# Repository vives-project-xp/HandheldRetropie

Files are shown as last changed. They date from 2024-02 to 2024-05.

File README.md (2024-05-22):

# HandheldRetropie
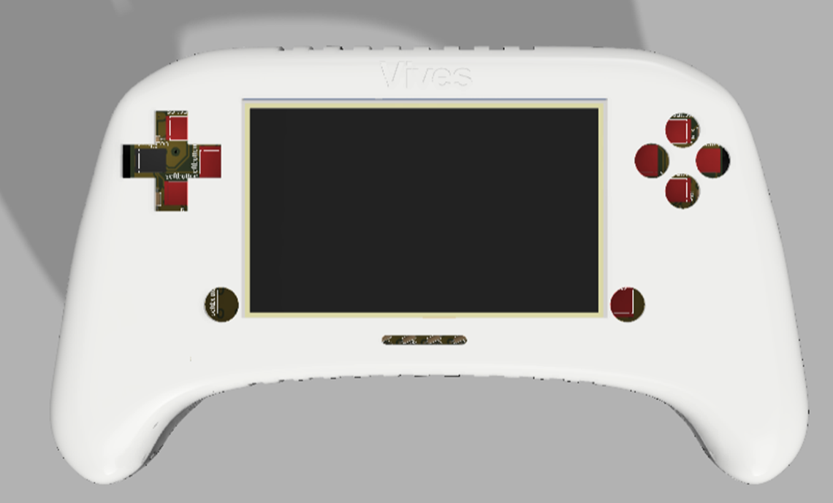
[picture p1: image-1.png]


These pictures are early renders of how the project should look.

## Contents

1. Introduction

2. The Team

3. Features

4. Software

5. 3D prints

6. PCB design

7. Hardware

8. setup

9. Tests

10. BOM

11. Information about the project

## Introduction
Welcome to the RetroPie Project! RetroPie is a versatile software solution that allows you to transform your Raspberry Pi into a full-fledged retro gaming console. It takes you back to the golden days of gaming where the concept was very simple but still fun. So you can play all the classic games you want, from Tetris to Mario. It does take you back to your childhood.

## The team

Thibaut Schroyens: Scrummaster, PCB design

Ruben Belligh: 3D design

Joë Boone: electronics

## Features
 
- The console is battery-powered.
- You can  switch the batterys.
- Designing PCB so that it takes up as little space as possible.
- Custom made casing.
- Uploading new games trough wifi.
- Battery indicator.
- Active cooling with PWM fans.
- Build in speaker.

## Software
One of the essential parts of the Retropie and maybe the beating heart of the project is the emulator. This is a software that makes it possible to put older games on a recent console. They actually form a bridge between the present and the past. This allows gamers to enjoy old games without playing on an old console. There will be a program running parallel with the games that calculates a PWM signal for cooling the system. This is calculated by the temperature inside the processor. the hotter it gets, the higher the PWM duty cycle gets, and thus cooling the system more.

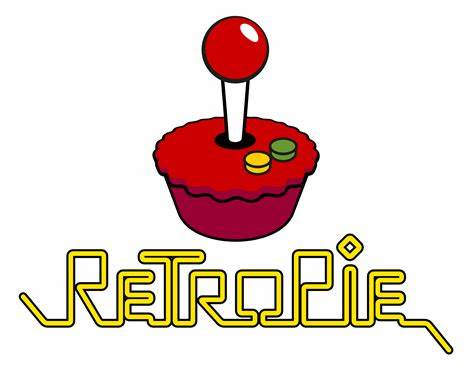
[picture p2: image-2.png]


## 3d prints
We've devided the 3d print in multiple parts so that these are easier to print. That's why there are 6 diffrent parts for the controller itself. The rest of the prints are the buttons. The controller can be connected trough connecting points that need to be glued together, this is only for the top side. The bottom side will be mounted with screws to the topside.
All of our prints were designed with fusion 360, the instructions to design certain models is in the 'handleiding fusion 360' folder.

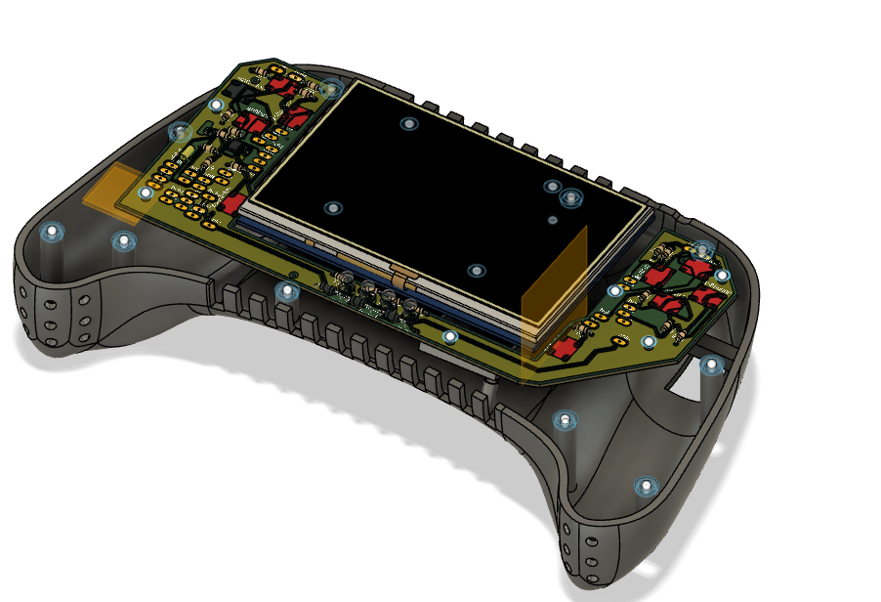
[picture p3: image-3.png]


## PCB design
Our pcb is also designed with fusion 360. The instructions to design 1 yourself are also in the 'xxxxxxxxxxxxxxxxxxxxx' folder. Our pcb holds all the buttons, the amplifier and the battery indicator. The PCB also has some holed that are provided to mount the pcb to the 3d case.

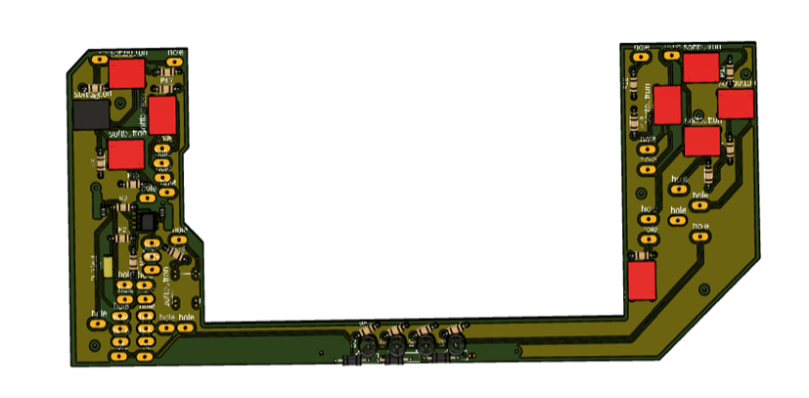
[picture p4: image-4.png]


# Hardware
Since the batterys operate at a voltage between 7,4V to 8,2V we need an inverter so that we can create a 5V circuit since most components only work with 5V. The sound is produced by our own aplifier system and a small 8 Ohm 1 Watt speaker. We have PWM fans that are spinning accordanly to the CPU temperature. To monitor our battery life we are using an led-indicator, which simpely uses resistors,leds and diodes

## Setup
-emulator install
-mounting everything at place x

## Tests
since we have a gathering of small projects fused in to 1 we had to test multiple components and circuits.
-converter
-amplifier
-screen
-emulator
-batterys
-3d prints

## BOM
This is the material we used to make our retropie. Of course, the 3D design will also be printed, but it is not included in the list.
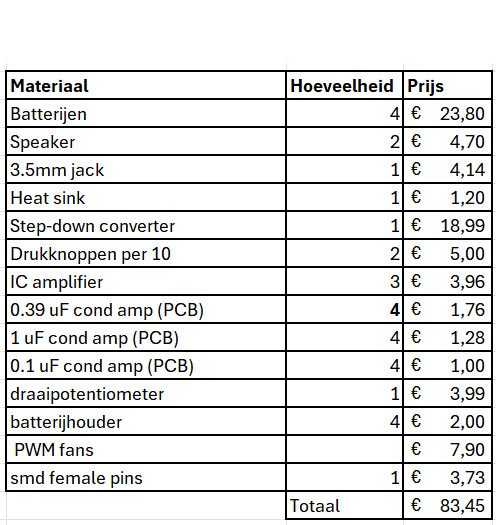
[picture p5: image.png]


## Information about the project
If you would like more information about our project, please refer to our GitHub.

https://github.com/vives-project-xp/HandheldRetropie

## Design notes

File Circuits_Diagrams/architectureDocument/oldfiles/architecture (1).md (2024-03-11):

 
 <h1>Architecture Document </h1>
 <h2>1. Functie, Product, Systeem</h2>
 <p>Algemene voorstelling van ons project.</p>
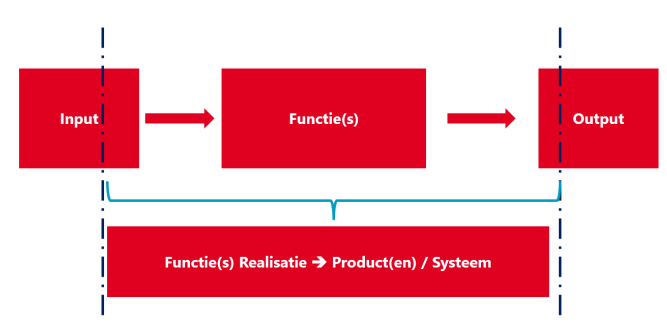
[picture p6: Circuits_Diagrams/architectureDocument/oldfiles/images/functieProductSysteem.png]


<h2>2. Input/output lijst</h2>

| Inputs | Outputs |
| --- | ---
|On/Off Button |LED battery indicator
|Start Button |Display
|Select button |Sound
|Play buttons (4) (shoulder buttons, joypad, normal buttons) |refrigeration
|Charge Input |
|USB Input |
|Battery Indicator  |
|AUX (Uitbreiding)  |

<h2>3. Direct/Indirect functions</h2>

|Direct | Indirecte
|--- | ---
|Audio | USB-c Voeding
|Emulator | 3D-Print behuizing
          | Battery

<h2>4. Architectuur</h2>

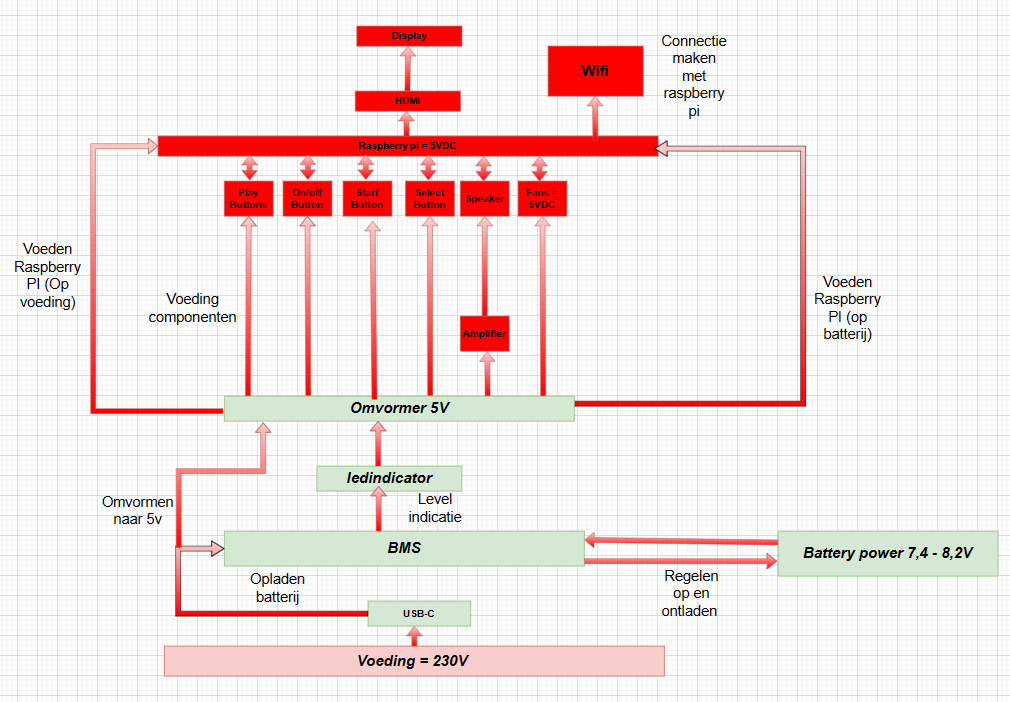
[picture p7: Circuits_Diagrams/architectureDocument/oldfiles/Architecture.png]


<h2>5. I/O overzicht </h2>
<h2>6. Power overzicht</h2>

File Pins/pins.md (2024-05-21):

<p> Dit zijn de pinnen die je moet gebruiken kijk naar de datasheet van de Raspberry PI voor alle pins.</p>
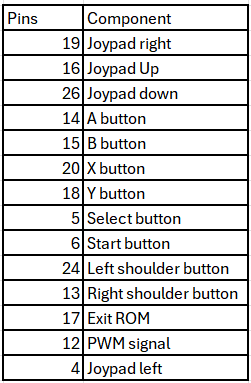
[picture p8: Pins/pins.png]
Beschrijving van de afbeelding


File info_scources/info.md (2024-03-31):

Website stappenplan gameconsole bouwen:
https://portablegear.nl/achtergrond/18218/retropie-gameconsole-bouwen/

https://www.instructables.com/Easy-Retro-Console/

filmpje retropie:
https://youtu.be/gkook0l_gsM

amplifier: 
https://www.circuits-diy.com/1-watt-amplifier-circuit/

pinnen raspberry:
https://roboticsbackend.com/raspberry-pi-3-pins/

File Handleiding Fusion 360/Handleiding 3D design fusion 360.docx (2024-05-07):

Handheld Retropie :

3D design fusion 360

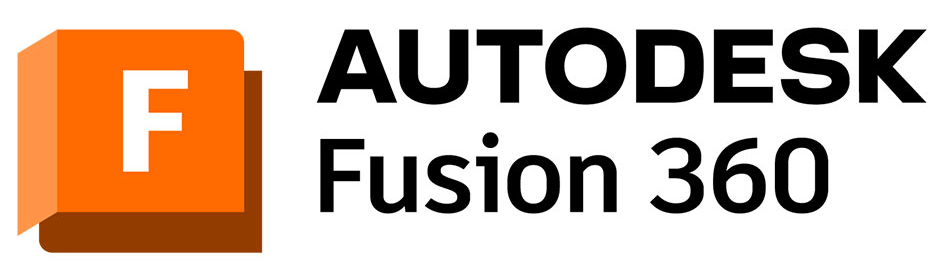
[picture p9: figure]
Autodesk - Fusion 360 - New license

# 1. Inleiding

Welkom bij ons project waarin we retro Gaming een nieuw leven in blazen. In dit document zullen we ons vooral concentreren op het 3D printen van de controller van onze Retropie. De behuizing is niet alleen functioneel, maar bevat ook de stijl die een controller moet hebben. Met behulp van Fusion 360 en 3D printers kunnen hebben we de vrijheid om onze ideeën werkelijkheid te laten worden. Hier zullen we het hele proces uitleggen van begin tot eind, iedereen kan dit maken of je nu een beginnende of ervaren ontwerper bent.

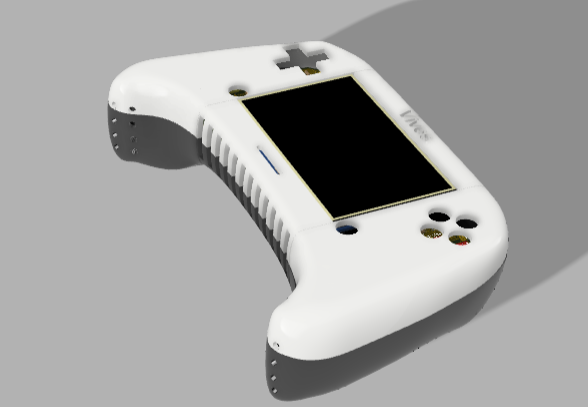
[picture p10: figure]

# 2. Fusion 360

## 2.1 Wat is Fusion 360

Fusion 360 is een software programma voor het ontwikkelen van 3D prints en PCB’s. Het biedt een uitgebreide set tools voor het ontwerpen van 3D-modellen. Er wordt voor Fusion 360 gekozen omdat er ook een PCB zal moeten ontwikkeld worden, hiermee kan je het PCB in de 3D print plaatsen waardoor je virtueel een volledig afgewerkt product hebt. Dit handig omdat je zo makkelijker je bevestigingspunten kan maken.

## 2.2 Installeren Fusion 360

Hierin zullen we uitleggen hoe je Fusion 360 kan installeren en je Education license kan verkrijgen.

1. Ga naar de website van Fusion 360. Zie hieronder de URL:

Autodesk Fusion | Free Software for Students and Educators | Autodesk (https://www.autodesk.com/campaigns/education/fusion-360)

2. Druk op “Download Autodesk Fusion”

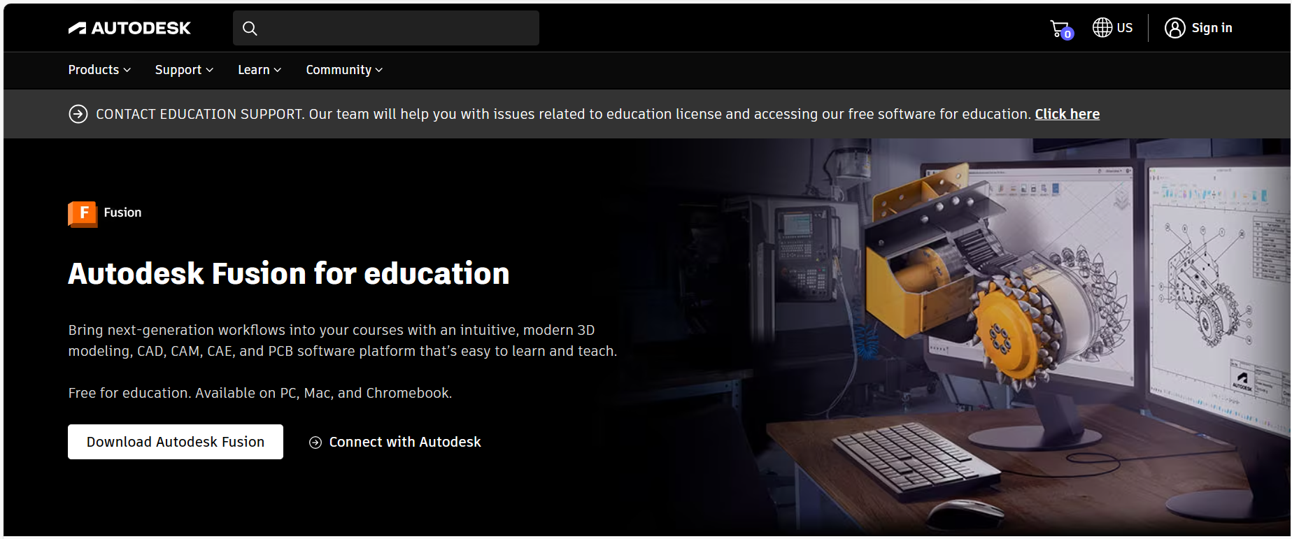
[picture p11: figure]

3. Druk dan op get started

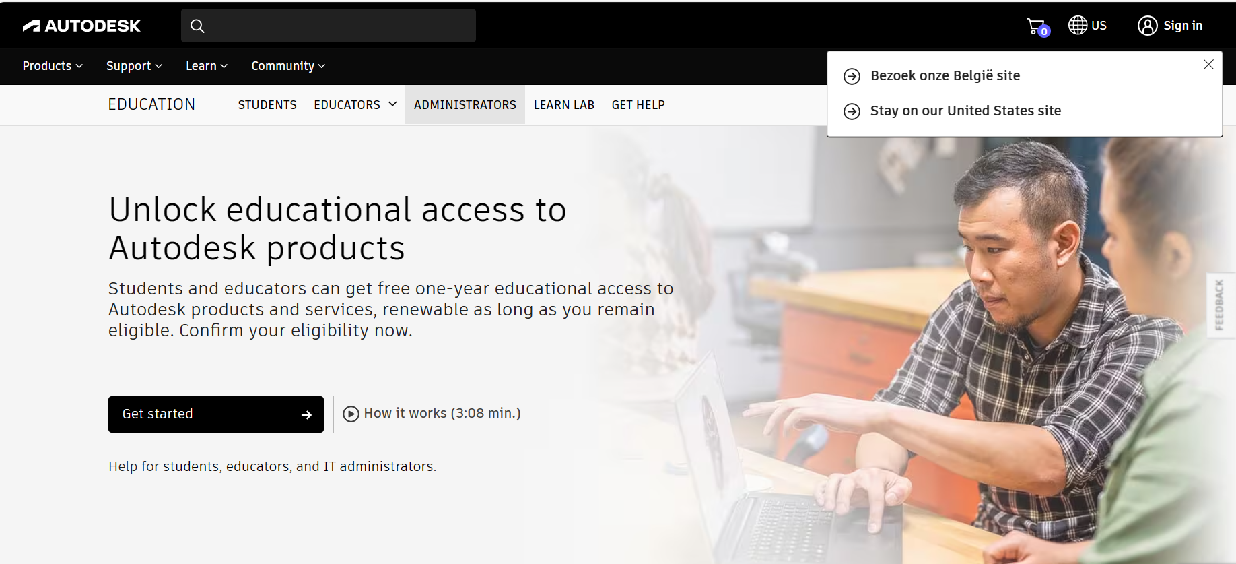
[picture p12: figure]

4. Vul je email adres in dat je wil gebruiken dit hoeft niet je email adres van school zijn. Druk daarna “I agree tot he Autodesk privacy-statement”

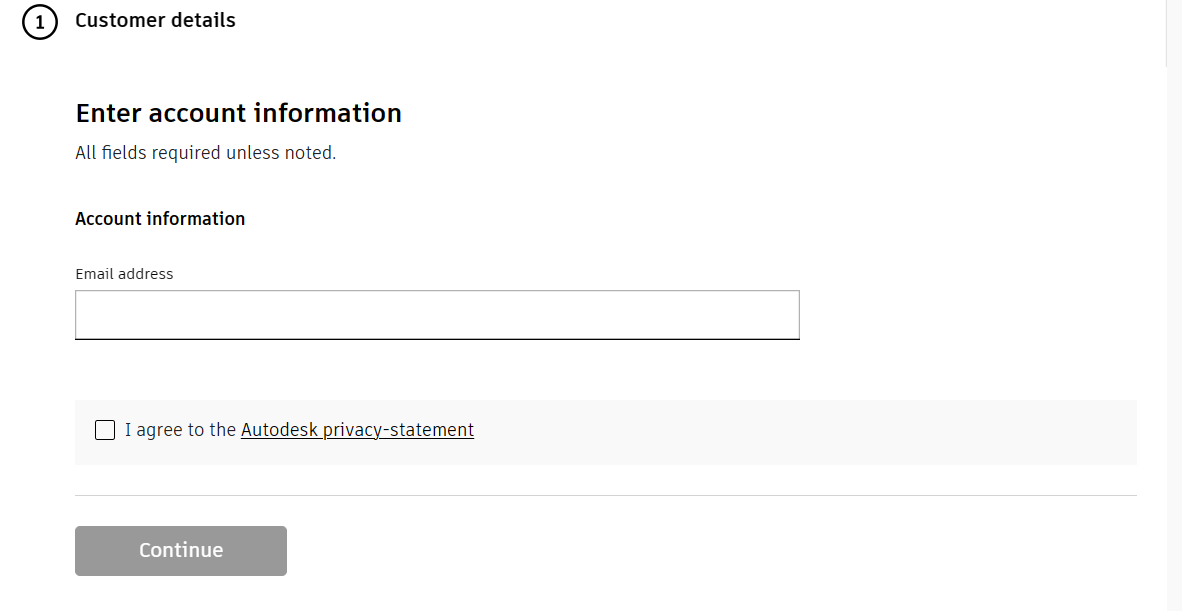
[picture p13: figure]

5. Vul je Voornaam en achternaam in en bij Eductational Role duid je Student aan.Vul daarna je verjaardagdatum in, druk dan op Continue.

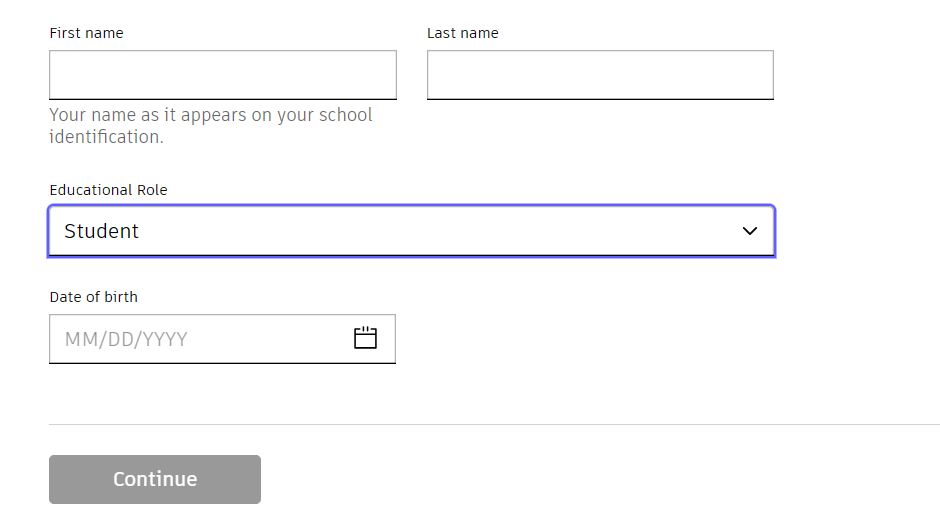
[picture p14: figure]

6. Geef dan je schooladres in, en duidt dan alles aan zoals hieronder op de afbeelding staat. Bij Graduation date zet je de datum wanneer je vermoedelijk zal afstuderen. Selecteer het vakje en druk op Continue.

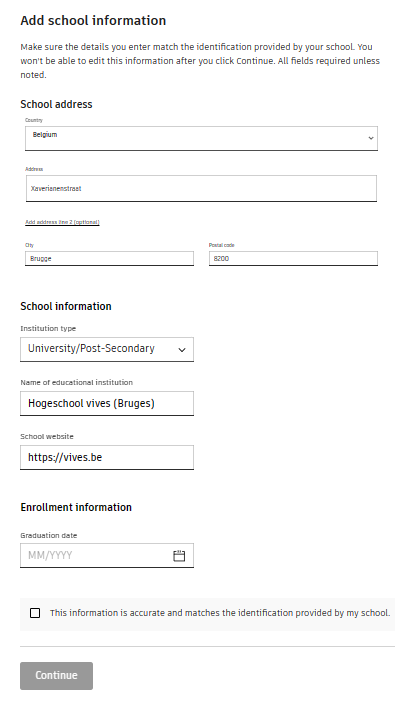
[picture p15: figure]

7. Daarna zal je dit venster krijgen en zal je op Continue moeten drukken. Toledo zal dan openen en je zal moeten inloggen.

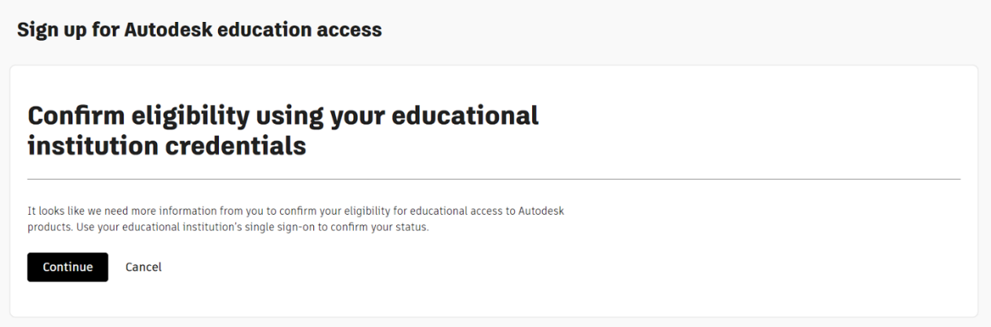
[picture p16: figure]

8. Als je ingelogd bent ga je terug naar het tablad autodesk en zal er een pop up geopend worden. Druk op submit om de license te verkrijgen.

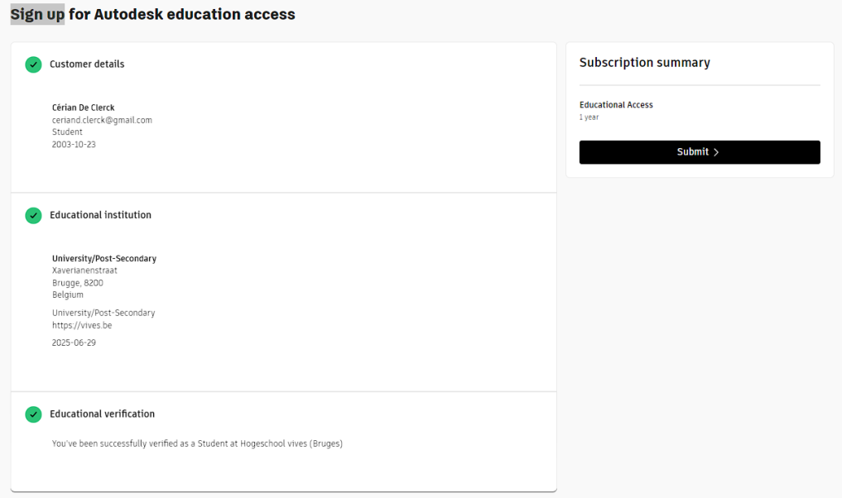
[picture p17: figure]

9. Je zal dan een email krijgen om je account aan te vullen met een paswoord.

10. Als je dit gedaan hebt zal je het volgende pop up venster tegenkomen

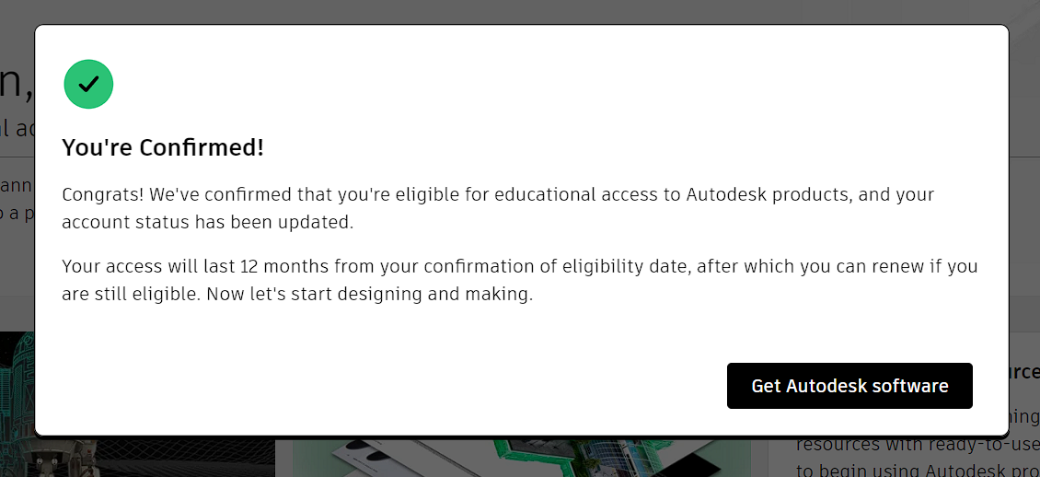
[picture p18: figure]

Druk op Get Autodesk software

11. Scroll dan naar beneden en zoek naar het volgende:

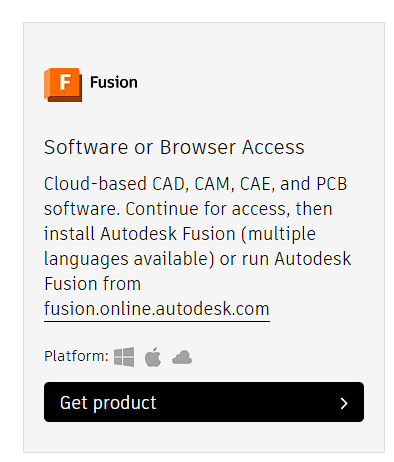
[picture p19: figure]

Druk op get product en dan wordt fusion gedownload.

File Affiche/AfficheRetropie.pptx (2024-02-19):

HandheldRetropie

Where nostlagia meets innovation

Dit is een gameconsole waar we oude games kunnen op spelen.


Deze console zal werken met een Raspberry pi. Hierop hebben we een emulator gezet waar alle games op staan.

Daarnaast zal deze werken op batterijen dus zal je overal en wanneer je wil kunnen gamen.

De retropie heeft natuurlijk een klein formaat dus zal hiervoor een PCB ontworpen worden om alles in de console te krijgen

P

Professionele bachelor
Elektronica-ICT

- Software Engineering
- Hardware Engineering
- Network- & System administration
- Artificial Intelligence
- Personal development

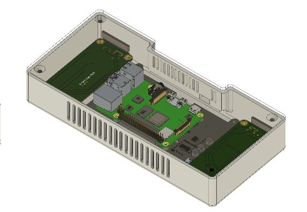
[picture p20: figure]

Instructies:
1. Pas de project titel aan en voeg een subtitel toe
2. Schrijf eronder een korte omschrijving van de probleemstelling, jullie uitwerking, de gebruikte componenten en welke leerstof jullie nodig hadden.
3. Vervang de 3 foto’s door mooie foto’s van jullie product/prototype.
4. Noteer jullie namen bij het team
5. Indien een leerlijn niet werd gebruikt in jullie project, vervang het vinkje dan door een leeg vierkantje.
6. Vervang de QR code door eentje die verwijst naar jullie GitHub repository.

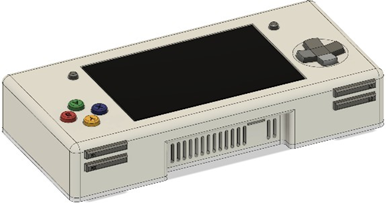
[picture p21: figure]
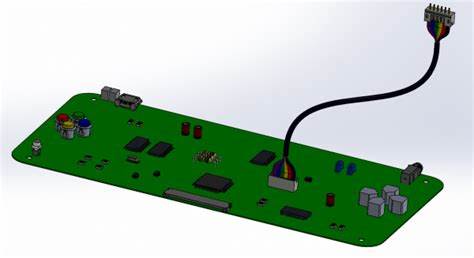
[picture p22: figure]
Camera met effen opvulling
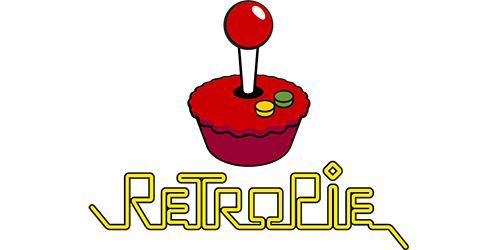
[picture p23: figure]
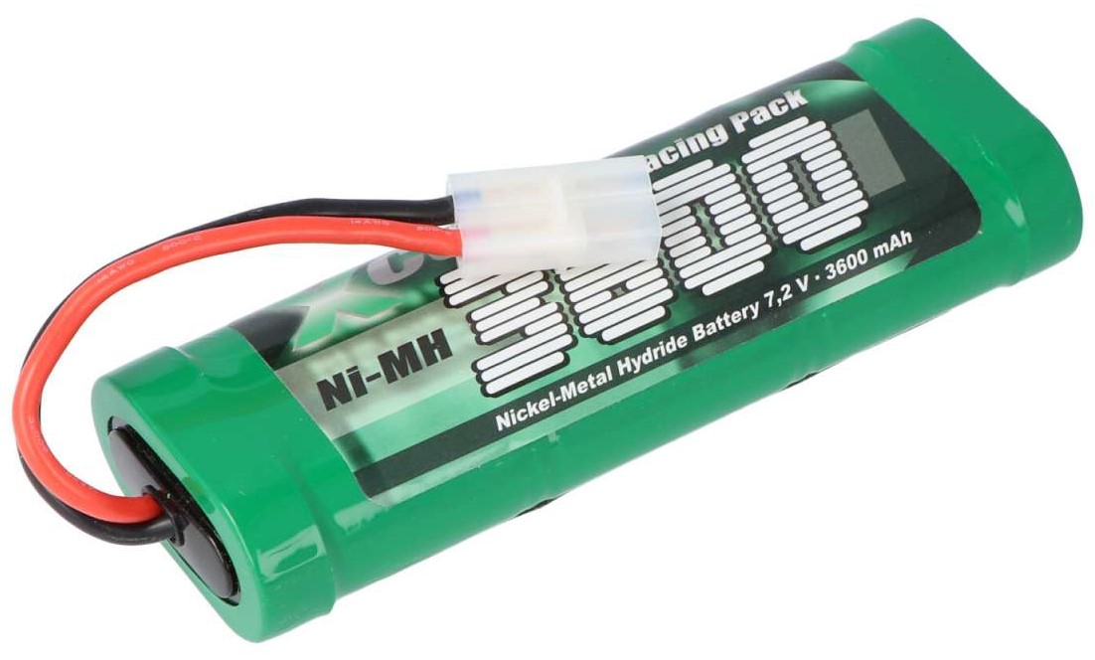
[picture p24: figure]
Camera met effen opvulling

Team
- Thibaut Schoyens , 2de jaars - Software en AI
- Ruben Belligh , 2de jaars - Netwerken
- Joë Boone , 1ste jaar – elektronica- ICT

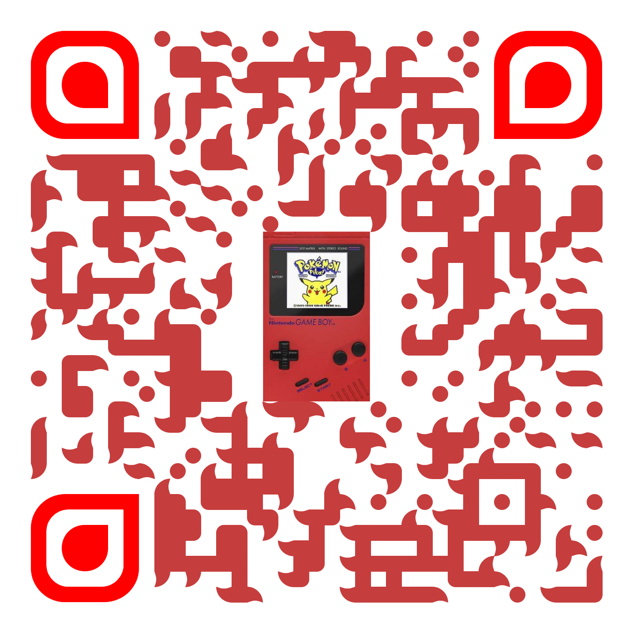
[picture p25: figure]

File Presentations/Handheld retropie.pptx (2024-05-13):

## Handheld retropie


Where nostalgia meets innovation.

Een project van VIVES hogeschool door Thibaut Schroyens, Ruben Belligh en Joe Boone


## Wie zijn wij?

Joe

- Ruben

- Thibaut

## Wat is ons project?

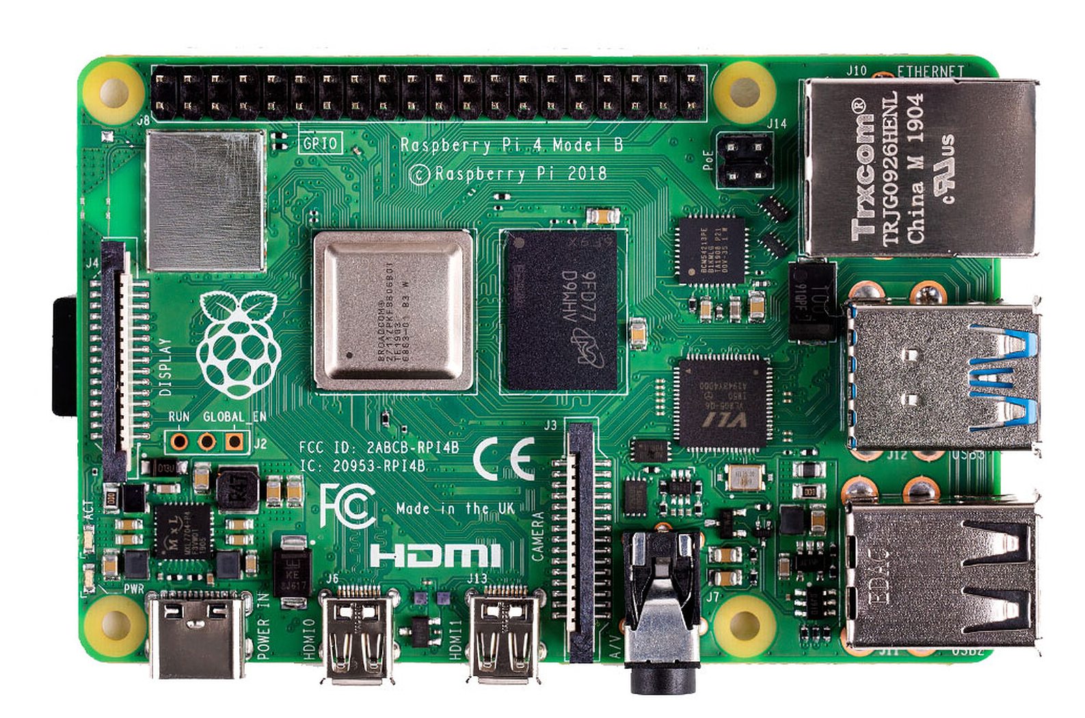
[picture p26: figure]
Raspberry Pi 4 Model B 8 Go
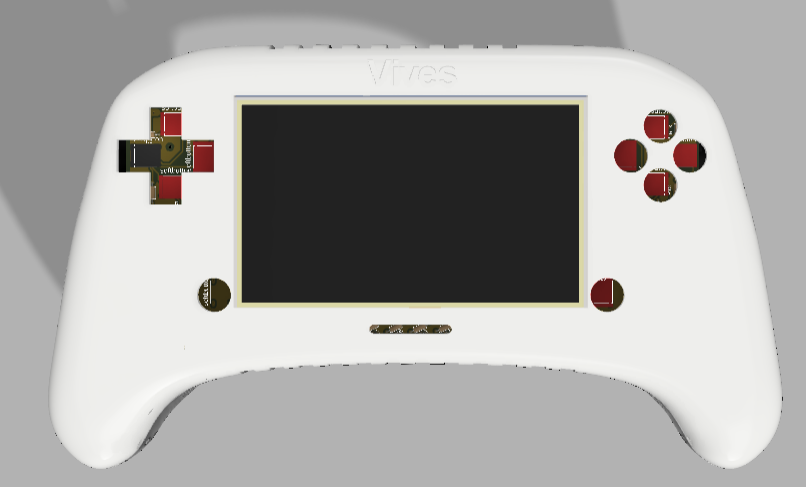
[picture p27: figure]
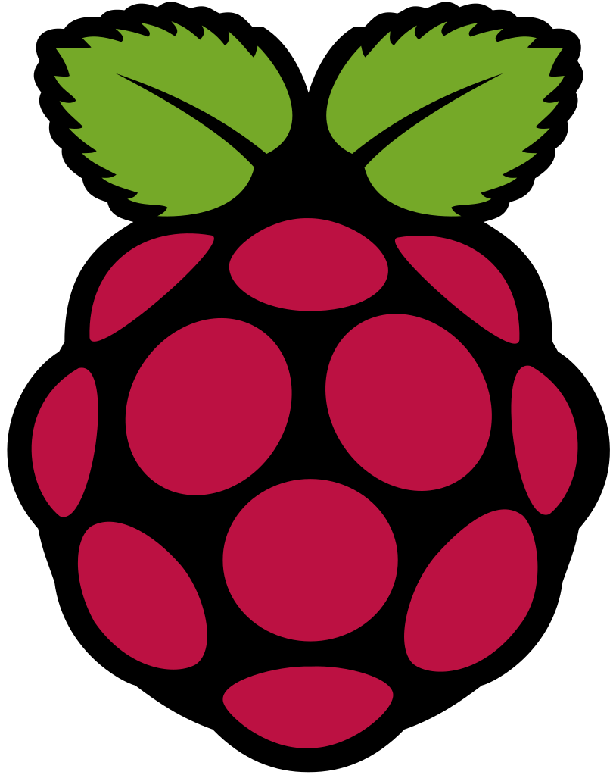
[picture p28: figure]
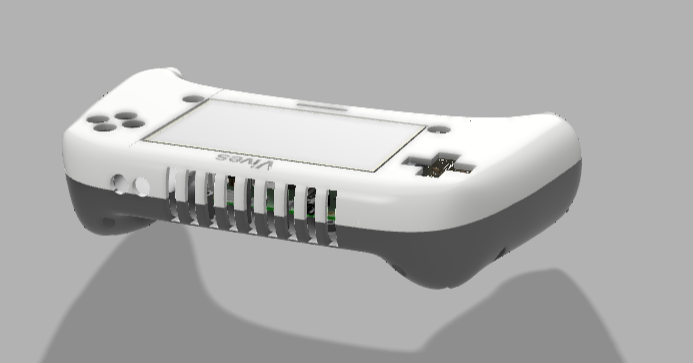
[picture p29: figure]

## Hoe werkt de RetroPi

## Waar zijn we al geraakt?


## Waar willen we naartoe werken?

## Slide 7

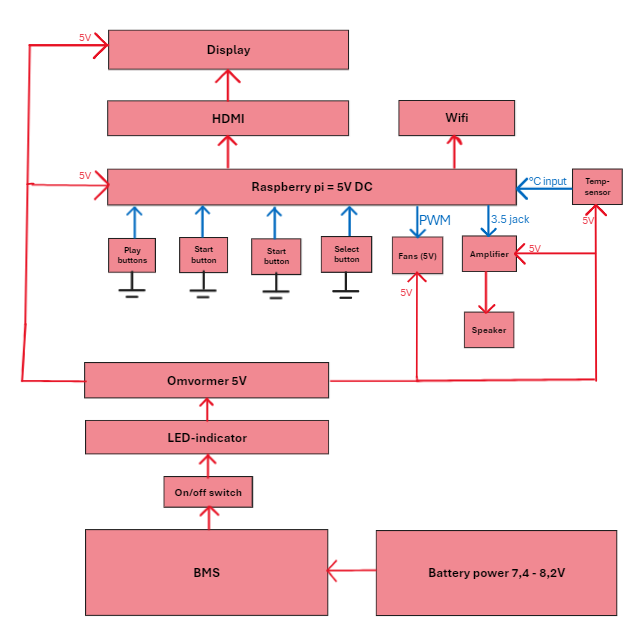
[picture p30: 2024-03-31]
Circuits_Diagrams/architectureDocument/oldfiles/Architecture_update2.png

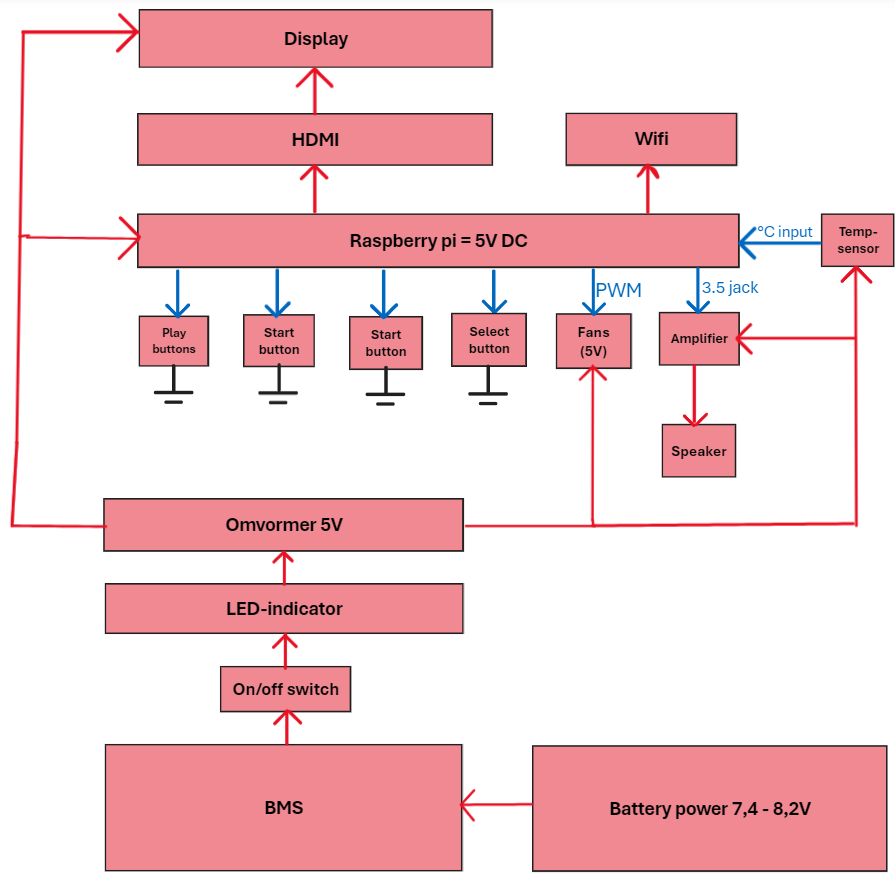
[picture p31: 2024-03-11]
Circuits_Diagrams/architectureDocument/oldfiles/update_architecture (1).png

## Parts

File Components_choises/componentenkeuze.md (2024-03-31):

# Componentenkeuze

## 1. Rasberry Pi4 model B

## 2. Batterij

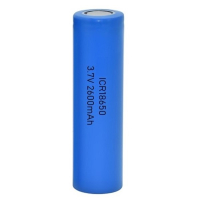
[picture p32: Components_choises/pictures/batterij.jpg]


We hebben de 18650 batterijen gekozen omdat deze niet veel plaats innemen en een grote capaciteit hebben, we zullen van deze batterijen 2 groepen van 2 in serie zetten. De 2 groepen zullen in parallel staan, hierdoor verdubbelen we de spanning en de capaciteit.

## 3. Speaker
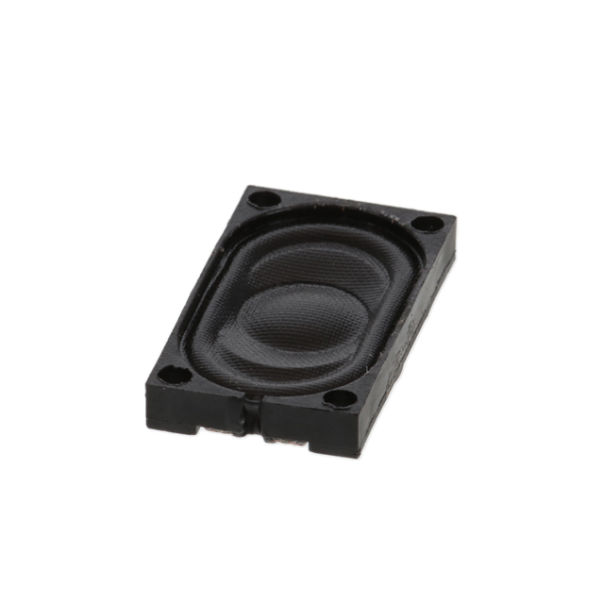
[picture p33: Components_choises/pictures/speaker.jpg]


We hebben gekozen voor een 8ohm + 1 watt speaker, dit door het compacte formaat. We zullen hier 2 van gebruiken in de retropie. Elk aan een kant van de retropie.

## 4. Step down converter

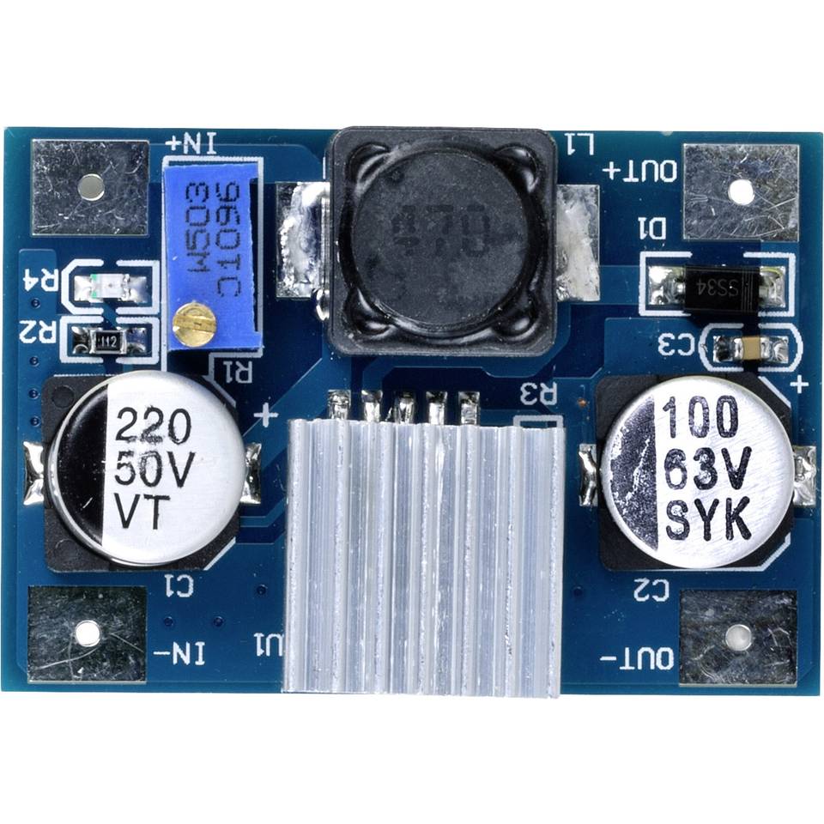
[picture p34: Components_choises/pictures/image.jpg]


Ingangsspanning: 3,5 - 35 VDC
Uitgangsspanning: 5 - 55 VDC (instelbaar)
Max. ingangsstroom: 3 A
We hebben dit component gekozen omdat onze spanning van de batterijen te hoog is, deze converter zal de spanning omzetten naar 5V, dit is bruikbaar voor al onze componenten.

## 5. Koeling

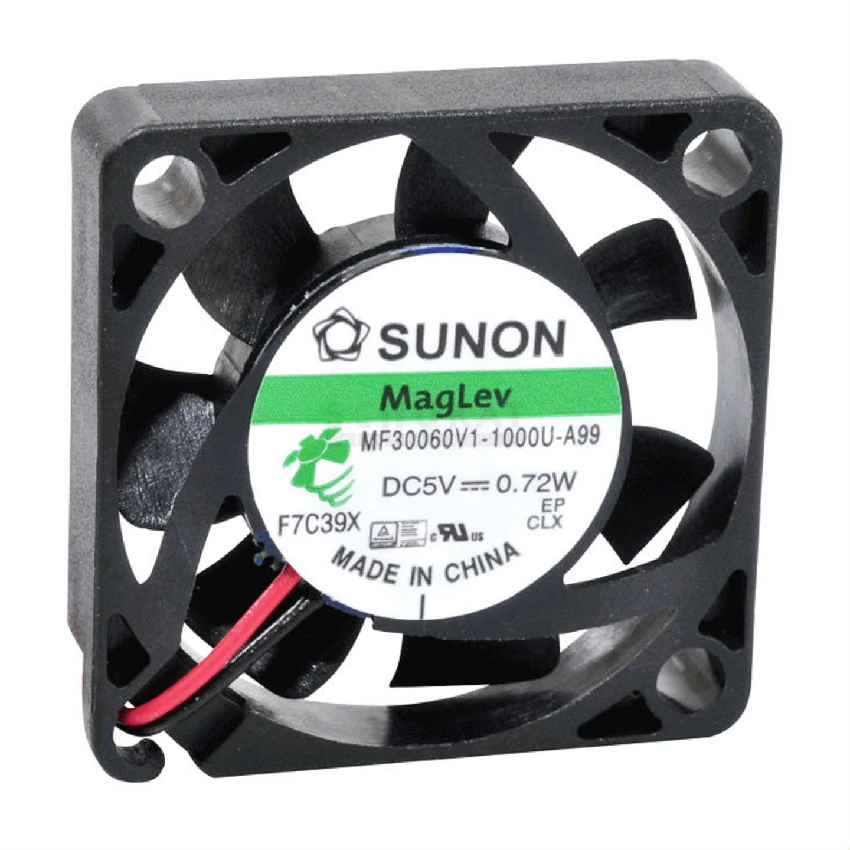
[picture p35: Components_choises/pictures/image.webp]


We hebben gekozen voor voor zeer kleine ventilatoren voor koeling (20x20x10mm). Aangezien we niet veel plaats hebben in de retropie is dit ideaal. Er zullen 3 fans aanwezig zijn. Deze worden gestuurd door een PWM signaal, beïnvloed door de ingebouwde temp sensor van de raspberry.

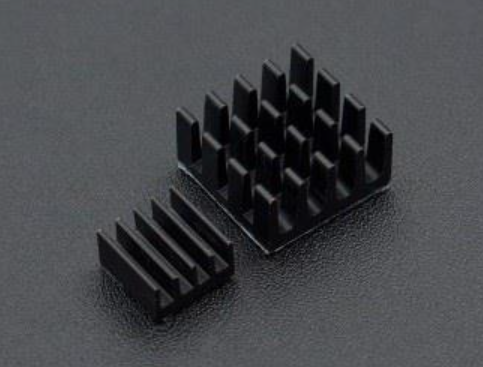
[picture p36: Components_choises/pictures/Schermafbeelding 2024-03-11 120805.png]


We hebben ook een heatsink gekocht om de warmte van de cpu af te voeren.

## 6. PCB

## 7. Temp-sensor

Deze is ingebouwd in de raspberry, en zal de temperatuur van de processor gaan bekijken en het PWN signaal gaan beïnvloeden.

## 8. 3D-prints

Wij zullen vooral PLA prints gebruiken, maar voor een doorzichtige achterkant te creëren zullen wij PETG gebruiken

## 9. On/off switch

We gebruiken hier een switch gebruiken in de vorm van een drukknop. Dit wordt geschakeled tussen de batterijen en de rest van de schakeling.

## 10. Leds

De leds zullen gebruikt worden in het battery level indicator systeem.

## 11. Weerstanden

We zullen weerstanden gebruiken in de battery level indicator, en de amplifiers.

## 12. Condensators

Deze worden gebruikt in de amplifier.

## 13. Amplifier IC

Het geluid wordt hier versterkt zodat het bruikbaar wordt, terwijl het in een kleine vormfactor blijft.

## 14. Buttons

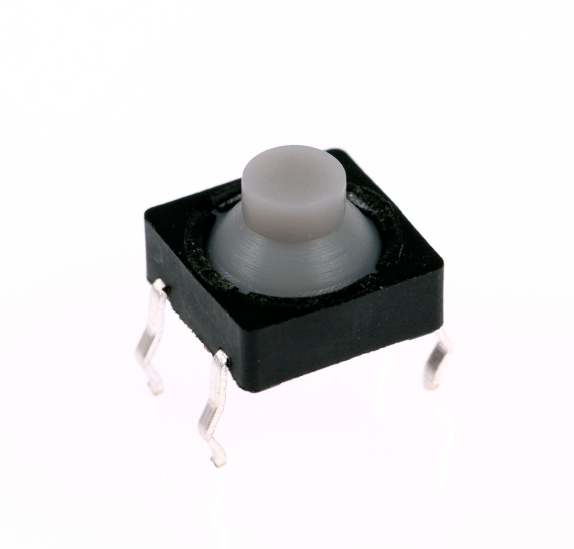
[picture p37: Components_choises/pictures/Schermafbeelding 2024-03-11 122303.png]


We hebben soft-touch buttons gekozen. Hierop zullen wij ge-3d printe buttons op monteren.

## 15. Display

Een 5inch scherm wordt gebruikt als output. Deze is vast gemonteerd aan onze raspberry pi.

## 16. HDMI to micro-HDMI

De raspberry pi 4 heeft een micro-hdmi aansluiting, het scherm die we gebruiken kan je hiermee makkelijk aansluiten via de hmdi poort die voorzien is.

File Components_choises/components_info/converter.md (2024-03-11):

## TC-9927160

datasheet: https://asset.conrad.com/media10/add/160267/c1/-/de/002481790DS00/datablad-2481790-tru-components-spanningsregelaar-tc-9927160-1-stuks.pdf 

Deze converter zal de spanningen omzetten naar 5V.

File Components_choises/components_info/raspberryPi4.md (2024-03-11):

##Raspberry pi 4 model B

Datasheet:
https://datasheets.raspberrypi.com/rpi4/raspberry-pi-4-datasheet.pdf 

de pinnen die wij gaan gebruiken:

1:

2:

3:

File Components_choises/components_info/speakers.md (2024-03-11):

## Ovale luidspreker

8 Ohm + 1 Watt
afmetingen: 30mm x 20mm x 5mm

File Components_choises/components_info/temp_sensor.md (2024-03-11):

## DS18B20

datasheet: 
https://asset.conrad.com/media10/add/160267/c1/-/en/002993930DS00/datablad-2993930-maxim-integrated-ds18b20-ds18b20-temperatuursensor-tube.pdf

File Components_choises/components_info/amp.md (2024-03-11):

## Amplifier system

Het systeem is ontworpen om op de PCB gemonteerd te worden met volgende componenten: 

## 1. IC amplifier

datasheet:
https://www.ti.com/general/docs/suppproductinfo.tsp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

## 2. condensator 0.39uF

## 3. condensator 1uF

## 4. condensator 0.1uF

## 5. draaipotentiometer

Dit om het volume te gaan beïnvloeden.

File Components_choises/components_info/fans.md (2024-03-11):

## 5V Cooling fan 20x20x10 2010 3pin

No datasheet (site instead) = https://www.vanallesenmeer.nl/Cooling-fan-20x20x10-5V

-fans working speed at X temp

-fans at X Hz (input). At X % speed

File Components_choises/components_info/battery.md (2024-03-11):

## 18650 battery

datasheet:
https://www.ineltro.ch/media/downloads/SAAItem/45/45958/36e3e7f3-2049-4adb-a2a7-79c654d92915.pdf

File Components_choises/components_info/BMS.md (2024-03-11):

## HX - 2S - A2

datasheet: https://images.100y.com.tw/pdf_file/54-HX-2S-A2.pdf

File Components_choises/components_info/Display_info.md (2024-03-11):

##5 inch touchscreen monitor 800x480

you can find datasheets in /componentenkeuze/display_datasheets

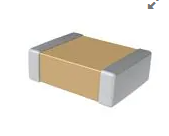
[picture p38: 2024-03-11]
Components_choises/pictures/amp_cond_0_1.png

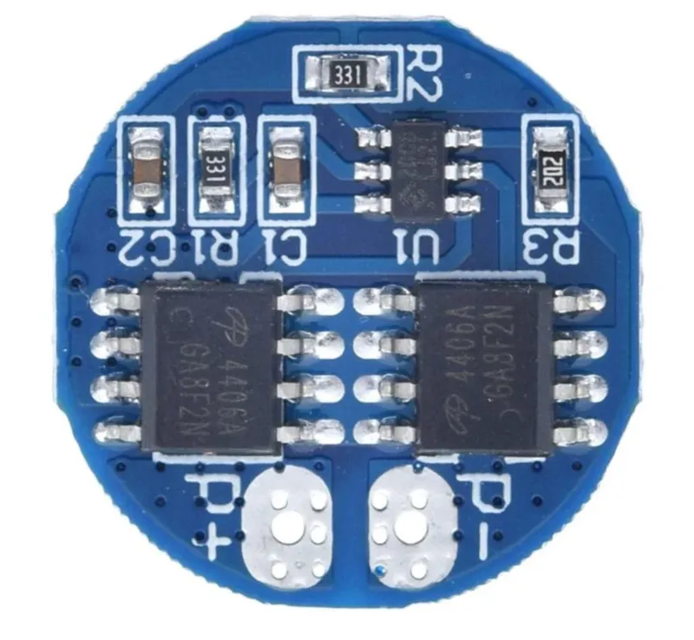
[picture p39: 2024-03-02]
Components_choises/pictures/BMS.webp

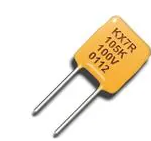
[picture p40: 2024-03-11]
Components_choises/pictures/amp_cond0_39.png

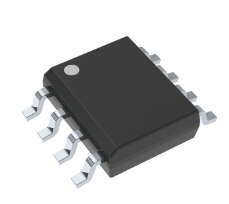
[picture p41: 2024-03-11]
Components_choises/pictures/amp_ic.png

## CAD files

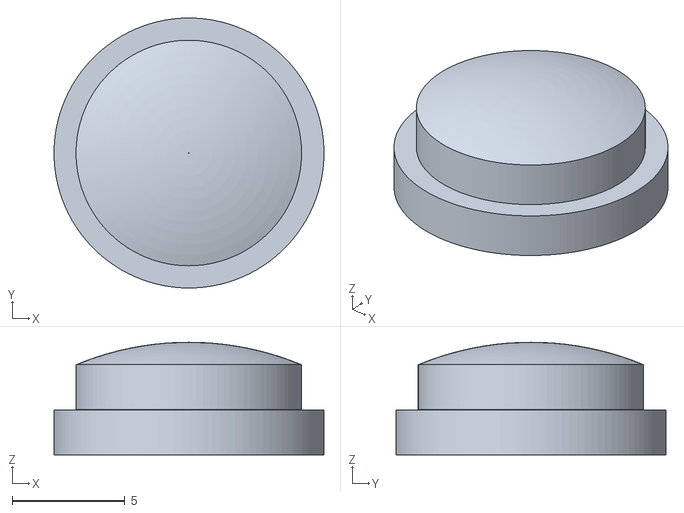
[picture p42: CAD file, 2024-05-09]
3D_files/Button Y v2.stl
12.0 x 12.0 x 5.00

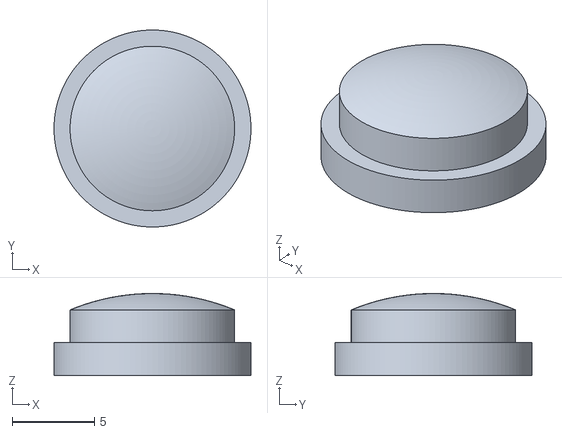
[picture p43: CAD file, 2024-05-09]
3D_files/Button B v2.stl
12.0 x 12.0 x 5.00

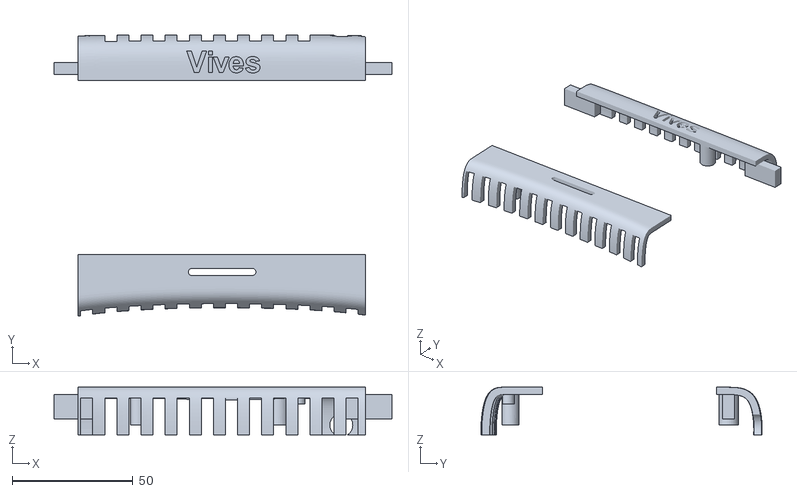
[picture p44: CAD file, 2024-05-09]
3D_files/Controller middenboven v1.stl
140.0 x 116.6 x 19.7

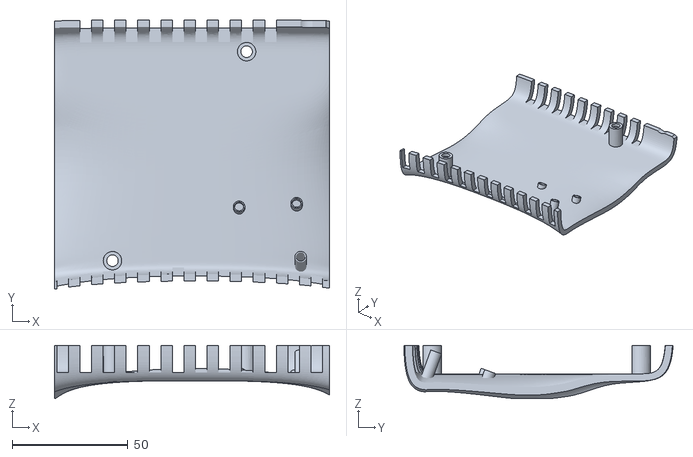
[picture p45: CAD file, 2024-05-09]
3D_files/Controller Middenonder v1.stl
119.0 x 116.5 x 23.0

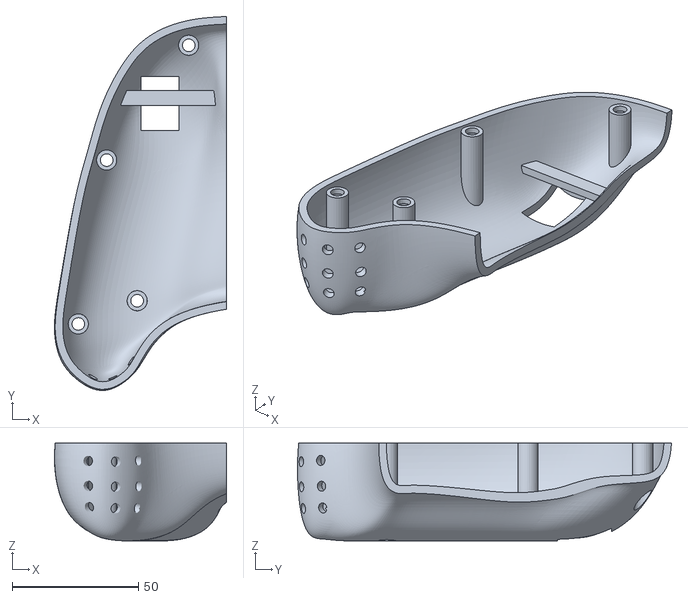
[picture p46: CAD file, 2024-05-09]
3D_files/Controller Linksonder v1.stl
68.2 x 148.3 x 38.8

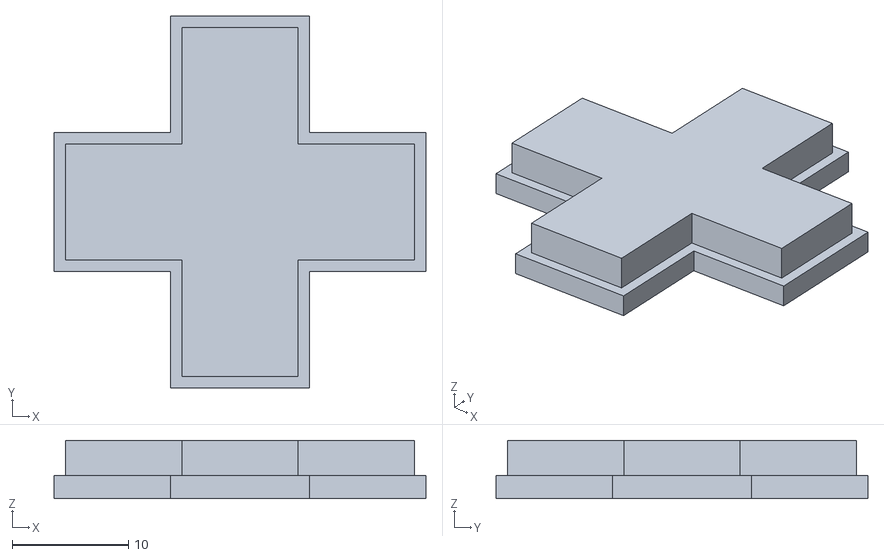
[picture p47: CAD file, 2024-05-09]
3D_files/Pad knop v6.stl
32.0 x 32.0 x 5.00

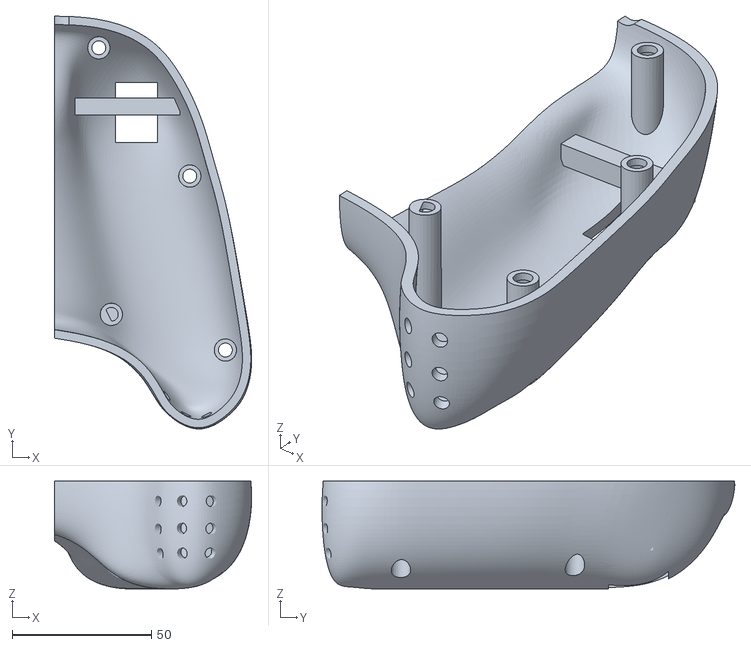
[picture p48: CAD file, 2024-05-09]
3D_files/Controller Rechtsonder v1.stl
70.9 x 148.3 x 38.8

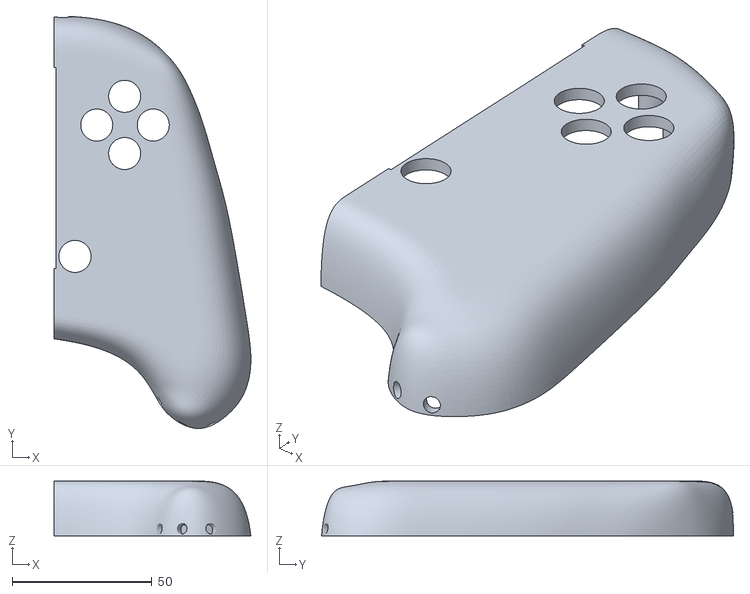
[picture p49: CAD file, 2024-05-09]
3D_files/Controller rechtsboven v1.stl
70.5 x 147.7 x 19.7

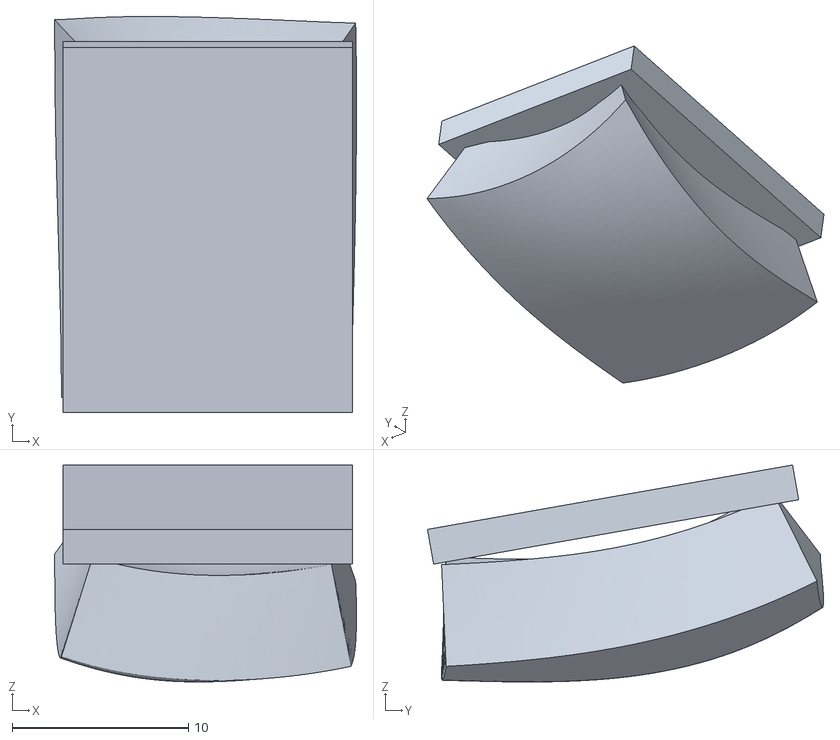
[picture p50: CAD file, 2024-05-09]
3D_files/Backbutton Left v4.stl
17.1 x 22.5 x 12.3

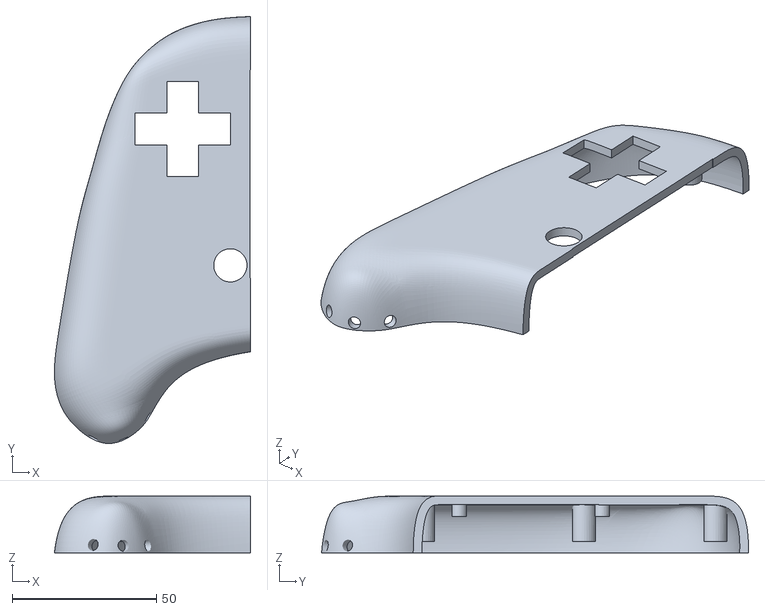
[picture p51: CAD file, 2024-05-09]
3D_files/Controller LinksBoven v1.stl
67.9 x 147.9 x 19.7

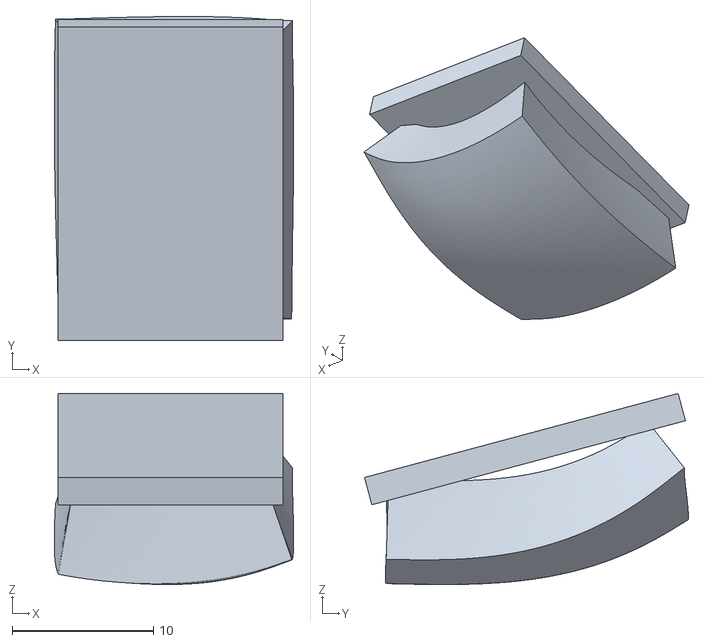
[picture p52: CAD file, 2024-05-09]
3D_files/Backbutton Right v7.stl
17.0 x 22.9 x 13.5

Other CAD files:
3D_files/Home Button v3.stl
3D_files/Button A v1.stl
3D_files/Select Button v1.stl

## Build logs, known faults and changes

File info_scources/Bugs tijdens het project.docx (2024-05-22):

Bugs tijdens het project

1. 3D design

- De achterkant werd zonder bevestigingspunten afgedrukt waardoor de Raspberry Pi niet kon bevestigt worden. (Opgelost)
- De knoppen waren niet hoog genoeg waardoor je de buttons niet kon indrukken. (Opgelost)

2. PCB design

- Geen problemen ondervonden

3. Testen van het werkelijke product

- Tijdens het testen van onze RetroPie startte deze eerst wel op de batterijen, maar daarna niet meer en bleef in een boot loop hangen. Toen we de console weer op het netstroom aansloten, startte hij wel op.
  - We dachten eerst dat het aan de step-down converter lag.
    - Test: We hebben de converter aangesloten op de stroombron in plaats van de batterijen en de RetroPie startte op, dus dit kan worden uitgesloten.

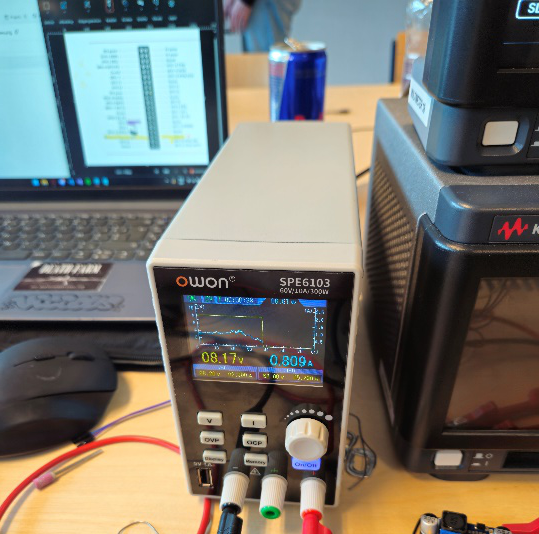
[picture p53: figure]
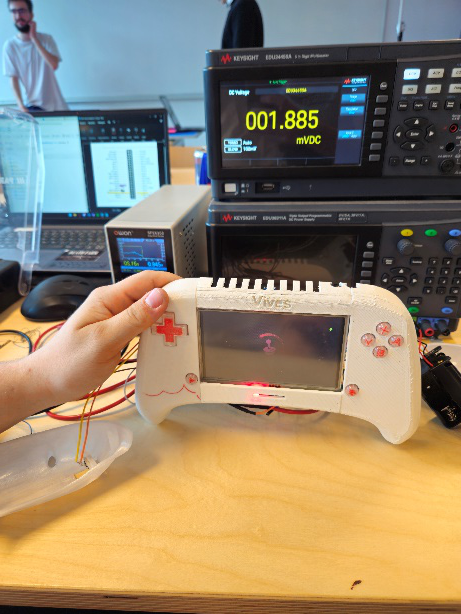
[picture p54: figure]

  - We hebben ook wat research gedaan op het internet en ontdekten dat de C-waarde van de batterijen mogelijk niet groot genoeg was. De C-waarde geeft de kracht van de batterij aan, oftewel hoeveel stroom de batterijen constant kunnen leveren.
    - Test: We hebben betere batterijen aangeschaft. Nu startte de console twee keer goed op en daarna weer niet, net zoals met de vorige batterijen. Dus dit was ook niet de oplossing.

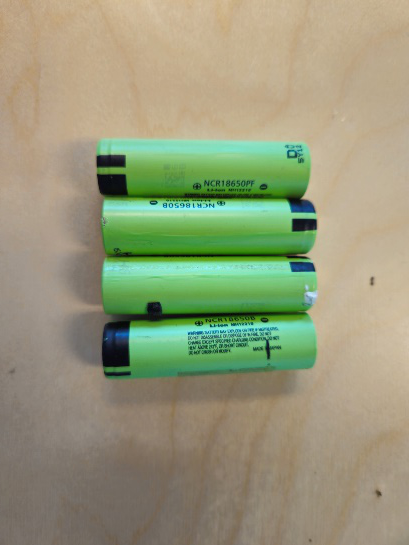
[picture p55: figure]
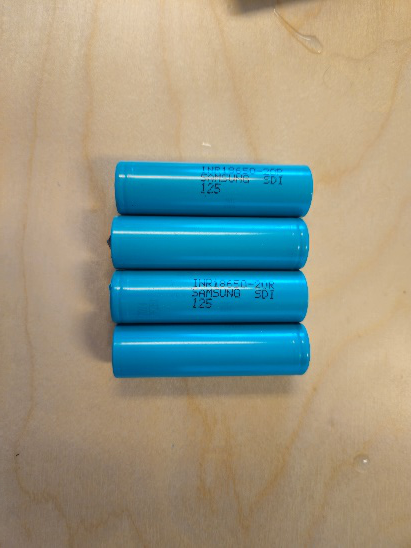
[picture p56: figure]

Oud Nieuw

3.1 Conclusie

Omdat we altijd batterijen hebben gebruikt die al eens in gebruik zijn geweest, denken we dat de batterijen aan het slijten zijn. Zodra één cel van een batterij minder capaciteit heeft, gaat hij de andere cellen opladen, waardoor er minder stroom naar onze controller kan gaan en deze dus niet kan opstarten. De oplossing zou dus zijn om nieuwe batterijen te kopen die nog niet gebruikt zijn.

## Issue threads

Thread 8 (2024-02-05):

Datasheet

RubenBelligh, 2024-02-05:
Uploaden of datasheets

RubenBelligh, 2024-02-14:
I searched for a suitable I/O expander and pushed the datasheet

RubenBelligh, 2024-02-15:
Added data from the battery

RubenBelligh, 2024-02-15:
Adding datasheet charger

RubenBelligh, 2024-02-15:
Added Info about the fan

Closed 2024-05-22.

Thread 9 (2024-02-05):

Battery charge/discharge

Tbo-s, 2024-02-05:
What kind of circuit/battery can we use for our handheld device so that it can charge and play at the same time.

Closed 2024-03-06.

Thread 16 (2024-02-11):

Creating Circuit for buttons

RubenBelligh, 2024-02-11:

RubenBelligh, 2024-02-12:
Find out how to connect the buttons to the PI.

RubenBelligh, 2024-02-12:
Find out how to connect the buttons to the PI.

RubenBelligh, 2024-02-12:
Draw a circuit for the buttons.

RubenBelligh, 2024-02-12:
Searching for a solution to too few pins on the Raspberry pi. (solution I/O expander).

RubenBelligh, 2024-02-14:
I made a circuit for the buttons with an I/O expander because there weren't enough pins. Now there is only 1 problem to get to the 3V3 pin, the display is already connected there.

BanaantjeJowie, 2024-02-26:
solution found for too few pins and buttons work on breadboard

Closed 2024-03-11.

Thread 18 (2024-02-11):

Making a working product

RubenBelligh, 2024-02-11:

RubenBelligh, 2024-05-17:
Afwrijven van het 3D design zodat het niet meer zo ruw aanvoelt.

RubenBelligh, 2024-05-18:
Bovenkant aan elkaar geplakt

RubenBelligh, 2024-05-18:
Moertjes geplakt aan de controller en dan de verschillende onderdelen bevestigd.

Tbo-s, 2024-05-21:
Solderen van de knoppen, weerstanden en draden op de PCB.

Tbo-s, 2024-05-21:
PCB in de controller plaatsen.

Tbo-s, 2024-05-21:
Batterijhouders in de controller plaatsen en deze solderen op de pcb.

RubenBelligh, 2024-05-21:
Batterijen plaatsen en alles een plaats geven in de controller.

Closed 2024-05-22.

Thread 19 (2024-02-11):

Test working product

RubenBelligh, 2024-02-11:

RubenBelligh, 2024-05-21:
Bij het testen zat de controller in een boot loop.

RubenBelligh, 2024-05-22:
We hebben betere batterijen erin gestoken maar deze zat ook weer in een boot loop. De batterijen zijn versleten

Closed 2024-05-22.

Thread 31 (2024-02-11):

Readme

RubenBelligh, 2024-02-11:

RubenBelligh, 2024-02-19:
Make a short Readme so that people at the open day have an idea of what the intention is.

RubenBelligh, 2024-05-21:
Aanvullen van de Readme over wat we allemaal gedaan hebben om tot het resultaat te komen zoals het 3D printen, PCB design en het elektronische gedeelte.

Closed 2024-05-22.

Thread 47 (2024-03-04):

fusion 360

RubenBelligh, 2024-03-04:
Youtube filmpjes kijken hoe ik met fusion 360 moet werken.

RubenBelligh, 2024-03-06:
Tutorial Day 1: kennis maken met fusion en welke funcities er allemaal zijn.

RubenBelligh, 2024-03-06:
Tutorial Day 2: Leren een foto overtekenen wat we ook zullen nodig hebben om onze controle te maken.

RubenBelligh, 2024-03-06:
Tutorial Day 3:  Leren werken met de sweep functie.

RubenBelligh, 2024-03-06:
Tutorial Day 4: Hierin heb ik gewerkt met de offset plan , de loft en thread functies

RubenBelligh, 2024-03-10:
Leren hoe je op fusion componenten moet kopiëren en in spiegelbeeld zetten

RubenBelligh, 2024-03-10:
Proberen een controller maken om te leren hoe je organisch moet tekenen.

RubenBelligh, 2024-03-11:
Leren hoe je de controller vanbinnen leegmaakt zodat de pcb erin en andere componenten erin kan

RubenBelligh, 2024-03-11:
Leren hoe je verluchtingsgaten moet maken in de controller voor de koeling

RubenBelligh, 2024-03-11:
Leren hoe je gleuven moet maken voor de verluchting.

Closed 2024-05-22.

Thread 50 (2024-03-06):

Documentation Test components

RubenBelligh, 2024-03-06:
Bevindingen van de testen documenteren

BanaantjeJowie, 2024-04-15:
pwm fans werken zoals het hoort

BanaantjeJowie, 2024-04-15:
spanningsregelaar is getest en we zijn tot de conclusie gekomen dat we de verkeerde hebben besteld

BanaantjeJowie, 2024-05-13:
drukknoppen werken zoals het hoort met de raspberry pi

BanaantjeJowie, 2024-05-13:
pwm signaal (uit de raspberry pi) om de fans aan te sturen uitgemeten en werken volgens verwachtingen. Eventuele aanpassingen aan parameters kunnen gemaakt worden met ssh verbinding met de rpi

BanaantjeJowie, 2024-05-13:
batterijenpacks zijn getest met 18650 batterijen met een spanning van 4V per batterij, 8V per 2.
ook zij deze getest met de spanningsregelaar en deze werkt volgens verwachtingen

Closed 2024-05-22.

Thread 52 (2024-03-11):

cooling fan script on startup

BanaantjeJowie, 2024-03-11:
this script and wiring is used to run the fans when the set temperature is reached. This program runs on startup of the rpi4.

BanaantjeJowie, 2024-03-11:
[script.md](https://github.com/vives-project-xp/HandheldRetropie/files/14561291/script.md)

BanaantjeJowie, 2024-05-13:
The script can be edited if necessariry using PuTTY or Visual Studio code with ssh connection.
It needs a default login,
user : pi
password : raspberry
ip : 10.10.253.149 (on devbit network)

Closed 2024-05-22.

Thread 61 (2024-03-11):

Documentation of Pins Used

Tbo-s, 2024-03-11:

BanaantjeJowie, 2024-05-13:
Button pins can be accessed using this line in console : `sudo nano /boot/retrogame.cfg`
The rest of the pins are found in `script.py`
**PINS USED:**
`
LEFT       4  # Joypad left
RIGHT     19  # Joypad right
UP        16  # Joypad up
DOWN      26  # Joypad down
LEFTCTRL  14  # 'A' button
LEFTALT   15  # 'B' button
Z         20  # 'X' button
X         18  # 'Y' button
SPACE      5  # 'Select' button
ENTER      6  # 'Start' button
A         24  # Left shoulder button
S         13  # Right shoulder button
ESC       17  # Exit ROM; PiTFT Button 1

PWM      12 # PWM signal for fans

`
**will be edited**

Closed 2024-05-22.

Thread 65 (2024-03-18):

3D design Fusion

RubenBelligh, 2024-03-18:
Het 3D model maken

RubenBelligh, 2024-03-18:
Eerste vorm gemaakt volgens afmetingen van de controller.

RubenBelligh, 2024-03-18:
Controller in twee gesplitst en in een aparte file plaatsen.

RubenBelligh, 2024-03-18:
Controller leeg maken en gaten maken voor de knoppen en de display

RubenBelligh, 2024-03-18:
Knoppen achteraan de controller toegevoegd. Nu is de vorm volledig af.

RubenBelligh, 2024-03-25:
Kijken hoe we de twee delen van de retropie aan elkaar kunnen bevestigen.

RubenBelligh, 2024-03-25:
Maken van de ronde buttons.

RubenBelligh, 2024-03-26:
Ik heb de Kruis button gemaakt op dezelfde manier als de ronde buttons met een pijltje erin.

RubenBelligh, 2024-04-14:
Zoeken hoe ik de bevestigingspunten ga maken in onze controller.

RubenBelligh, 2024-04-14:
Maken van de bevestigingspunten

RubenBelligh, 2024-04-15:
Input maken voor de volumeknop.

RubenBelligh, 2024-04-15:
Backbuttons maken voor de controller.

RubenBelligh, 2024-04-15:
Gat maken voor de powerbutton en voor de leds die  aanduidt hoeveel capaciteit de batterijen nog heeft.

RubenBelligh, 2024-04-17:
Ventilatiegaten maken onderaan in de controller, en bovenaan gleuven maken zodat er een goeie luchtstroom is.

RubenBelligh, 2024-04-23:
Gaten knoppen kleiner maken omdat de knoppen bij het testen er niet in pasten

RubenBelligh, 2024-04-23:
PCB en display in de controller plaatsen om zo de aansluitingen te kunnen maken.

RubenBelligh, 2024-04-23:
Kijken hoe we de batterijen kunnen plaatsen in de controller.

RubenBelligh, 2024-04-23:
De controller in het midden wat dikker maken omdat bij het testen er niet veel plaats tot geen plaats meer over was.

RubenBelligh, 2024-04-28:
Bevestigingspunten maken voor de Raspberry PI

RubenBelligh, 2024-04-28:
Onderaan openingen maken voor ventilatie en zodat het geluid goed hoorbaar is

RubenBelligh, 2024-04-28:
Uitzoeken hoe ik aansluitingen ga maken om de batterijen te kunnen vervangen.

RubenBelligh, 2024-04-28:
Gaten maken om de controller vast te maken met schroeven.

RubenBelligh, 2024-04-28:
In het midden aansluitingen maken zodat de verschillende onderdelen goed aan elkaar bevestigd blijven.

RubenBelligh, 2024-05-06:
Proberen samenvoegen van PCB met het 3D design en zo de nodige aanpassingen maken.

Closed 2024-05-22.

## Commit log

2024-02-06 Schema Battery
2024-03-11 updated_architecture
    deze zonder het oplaadsysteem. geupdated knoppen + on/off switch
2024-03-11 Delete Circuits-Schema's/updatedarchitecture.png
    letter groote updated
2024-03-31 3D files
    [Button A v1.3mf, Button B v2.3mf, Button X v2.3mf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]
2024-05-09 3D files 2.0
    [Backbutton Left v4.3mf, Backbutton Left v4.stl, Backbutton Right v7.3mf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]
2024-05-21 PCB schema
